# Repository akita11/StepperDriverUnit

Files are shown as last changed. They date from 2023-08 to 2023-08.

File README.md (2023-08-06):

# SteppterDriverUnit

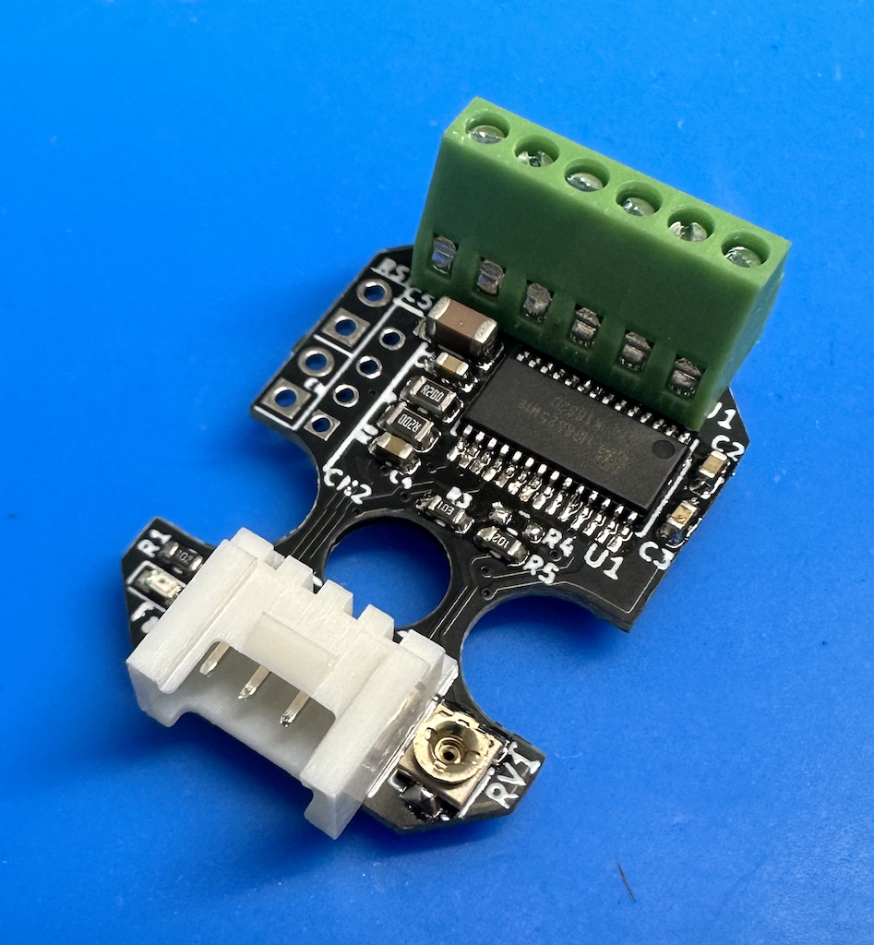
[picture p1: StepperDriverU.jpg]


ステッピングモータをGrove端子からの方向・パルスのみで制御できるUNITです。ドライバICはよく使われるDRV8825の互換IC(HR8255)を使用しており、マイクロステップ駆動も可能です。またイネーブル・リセットは別の端子から与えることもできます。

# 使用法（まずは使ってみる）

- 6pコネクタ（ネジ端子：基板裏面にシルク表記あり）に、ステッピングモータの電源(+12V等）とモータのA相・B相(各2本：計4本）のケーブルを接続します。
- Grove端子にマイコンなど(M5Stack等)を接続します（ここからの+5V給電が本体の動作に必要です）
- Grove端子の信号線(DIRとSTP)でモータの回転の向きとステップを制御します。DIR=0/1で回転方向を決定し（実際の回転方向がどちらが時計回りかはA相・B相の配線によって異なる）、STPの立ち上がり（0→1の変化)で1ステップ進みます。

Grove端子のピン配置（基板裏面にシルク表記あり）： STP/DIR/+5V/GND

# 使用法（詳細な設定など）

半固定抵抗（RV1）でモータの駆動電流を設定てきます。また動作異常時にはD1(Fault)が点灯します。

## 補助制御端子

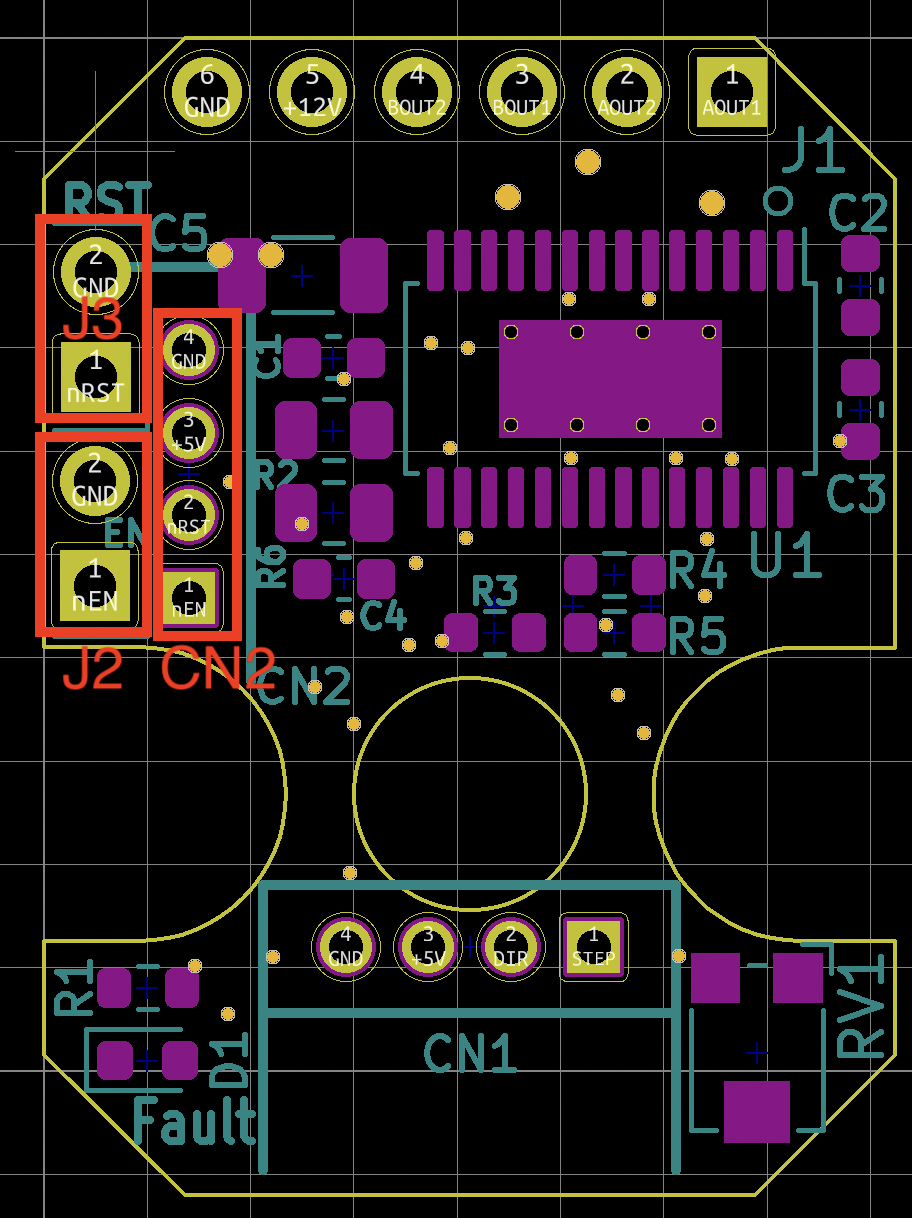
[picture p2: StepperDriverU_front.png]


- J2の2本をショートすると、ドライバICをdisable状態にしてモータの駆動をOFFにします。
- J3の2本をショートすると、ドライバICの内部状態をリセットします。
- CN2にもこの2本の信号線が引き出してあり、Grove端子をとりつけてマイコン等から制御することができます。このGrove端子のピン配置（基板裏面にシルク表記あり）： nEN/nRST/+5V/GND （nEN=0でドライバICがON、=1でOFF。nRST=0でドライバICをリセット、=1で通常動作）

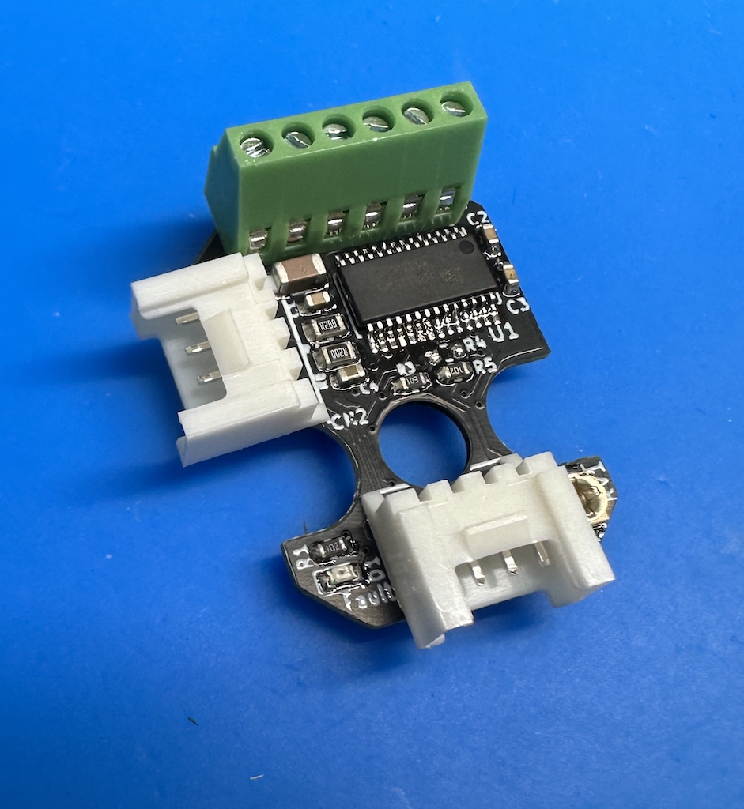
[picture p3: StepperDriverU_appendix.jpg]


## 駆動方法の設定

基板裏面の4つのソルダージャンパで、モータの駆動方法を設定できます。詳細はHR8825（またはDRV8825）のデータシートを参照してください。

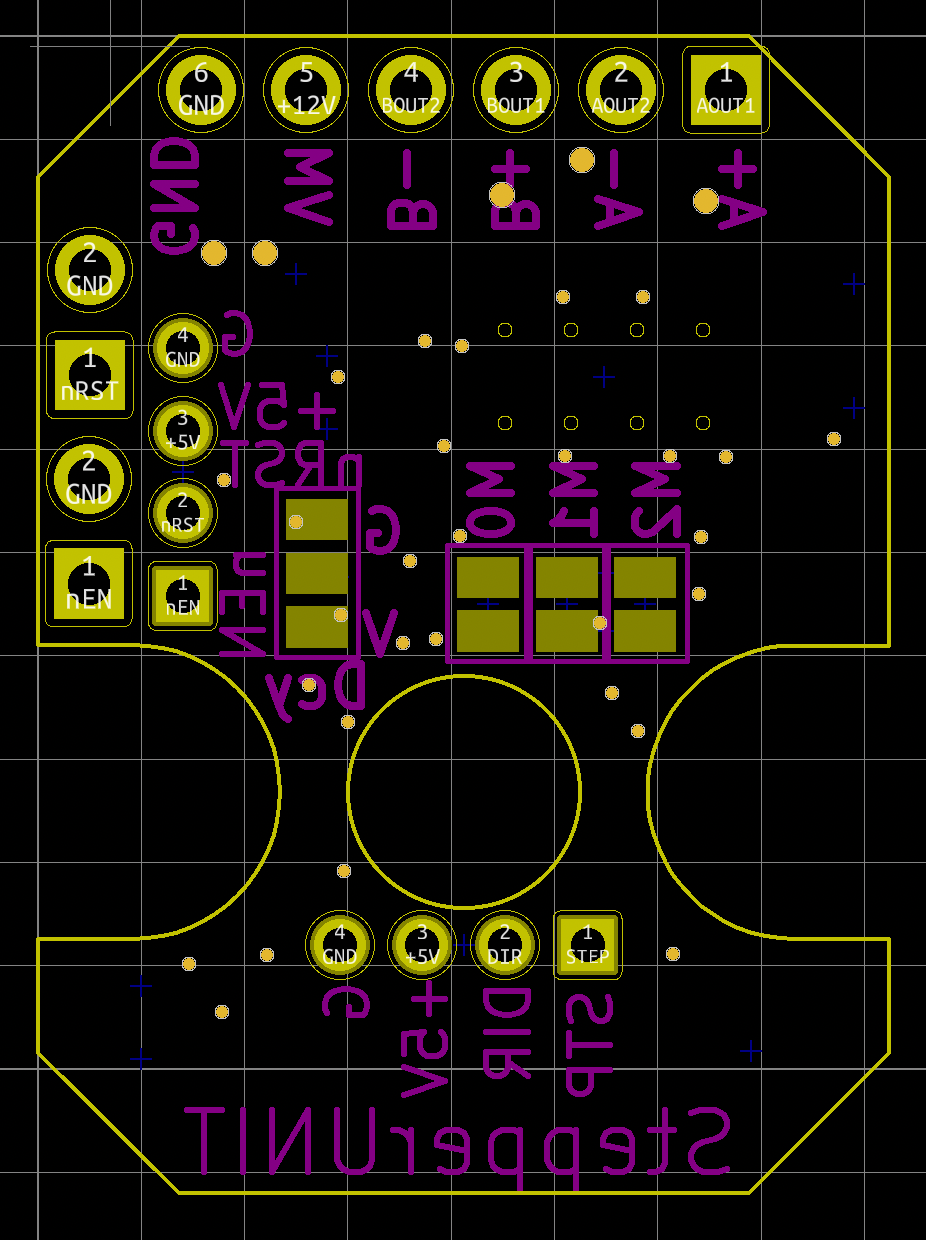
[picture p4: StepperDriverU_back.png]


- M0/M1/M2: マイクロステップの設定。（o=ショート、x=開放）

| M0 | M1 | M2 | マイクロステップ |
| -- | -- | -- | -- |
| x  | x  | x  | フルステップ |
| o  | x  | x  | 1/2ステップ |
| x  | o  | x  | 1/4ステップ |
| o  | o  | x  | 8 microステップ |
| x  | x  | o  | 16 microステップ |
| o  | x  | o  | 32 microステップ |
| x  | o  | o  | 32 microステップ |
| o  | o  | o  | 32 microステップ |

- Dcy: Decayモードの設定（G-中央間をショート=slow / V-中央間をショート=fast / ショートなし=mixed）

# Author

Junichi Akita (akita@ifdl.jp / @akita11)

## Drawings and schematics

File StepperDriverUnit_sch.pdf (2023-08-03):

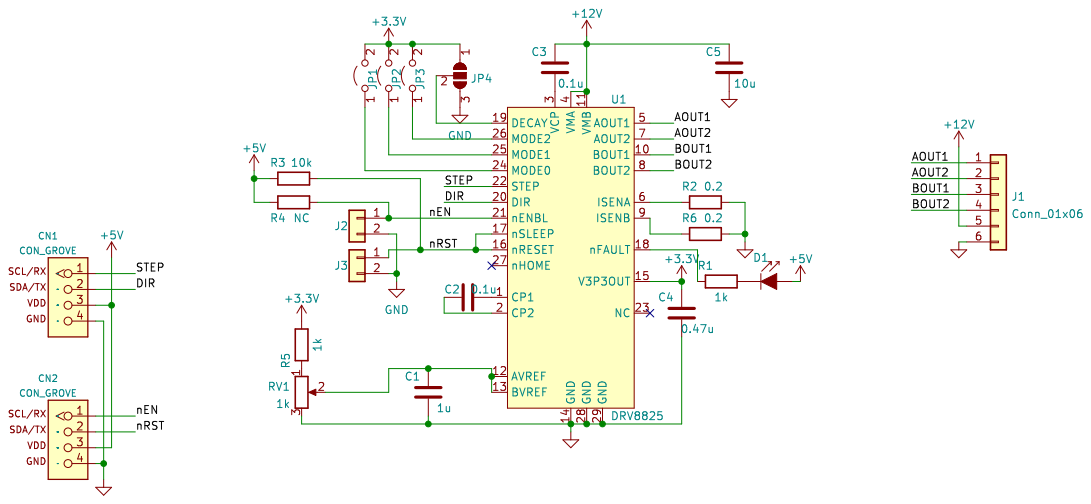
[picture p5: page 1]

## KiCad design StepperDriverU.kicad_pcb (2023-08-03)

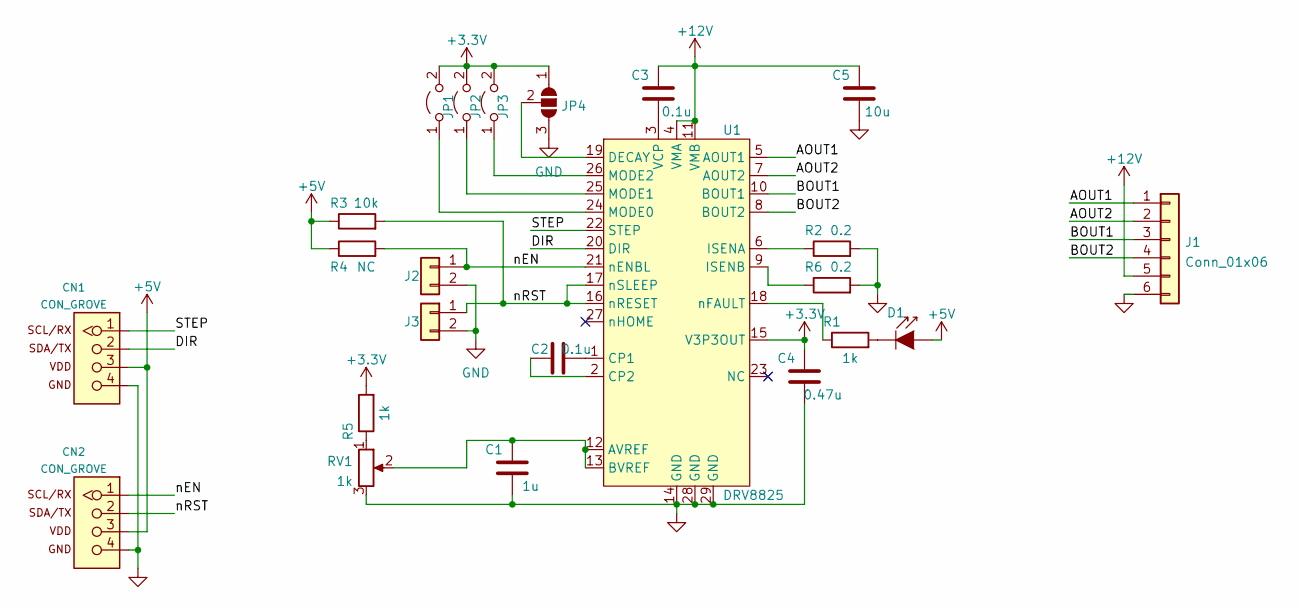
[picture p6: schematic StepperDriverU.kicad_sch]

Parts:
C1: 1u; C_0603_1608Metric
C2, C3: 0.1u; C_0603_1608Metric
C4: 0.47u; C_0603_1608Metric
C5: 10u; C_1206_3216Metric
CN1, CN2: CON_GROVE; CON_GROVE_H
D1: LED; LED_0603_1608Metric
J1: Conn_01x06; PinSocket_1x06_P2.54mm_Vertical
J2, J3: Conn_01x02; PinSocket_1x02_P2.54mm_Vertical
JP1, JP2, JP3: Jumper_2_Open; SolderJumper-2_P1.3mm_Open_Pad1.0x1.5mm
JP4: SolderJumper_3_Open; SolderJumper-3_P1.3mm_Open_Pad1.0x1.5mm
R1, R5: 1k; R_0603_1608Metric
R2, R6: 0.2; R_0805_2012Metric
R3: 10k; R_0603_1608Metric
R4: NC; R_0603_1608Metric
RV1: 1k; Potentiometer_Bourns_TC33X_Vertical
U1: DRV8825; HTSSOP-28-1EP_4.4x9.7mm_P0.65mm_EP2.85x5.4mm_ThermalVias

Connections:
+3V3: C4.2, JP1.2 (B), JP2.2 (B), JP3.2 (B), JP4.1 (A), R5.2, U1.15 (V3P3OUT)
+5V: CN1.3, CN2.3, D1.2 (A), R3.1, R4.1
+12V: C3.2, C5.2, J1.5, U1.4 (VMA), U1.11 (VMB)
/AOUT1: J1.1, U1.5 (AOUT1)
/AOUT2: J1.2, U1.7 (AOUT2)
/BOUT1: J1.3, U1.10 (BOUT1)
/BOUT2: J1.4, U1.8 (BOUT2)
/DIR: CN1.2, U1.20 (DIR)
/STEP: CN1.1, U1.22 (STEP)
/nEN: CN2.1, J2.1, R4.2, U1.21 (nENBL)
/nRST: CN2.2, J3.1, R3.2, U1.16 (nRESET), U1.17 (nSLEEP)
GND: C1.1, C4.1, C5.1, CN1.4, CN2.4, J1.6, J2.2, J3.2, JP4.3 (B), R2.2, R6.2, RV1.3, U1.14 (GND), U1.28 (GND), U1.29 (GND)
unnamed: C1.2, RV1.2, U1.12 (AVREF), U1.13 (BVREF)
unnamed: C2.1, U1.2 (CP2)
unnamed: C2.2, U1.1 (CP1)
unnamed: C3.1, U1.3 (VCP)
unnamed: D1.1 (K), R1.2
unnamed: JP1.1 (A), U1.24 (MODE0)
unnamed: JP2.1 (A), U1.25 (MODE1)
unnamed: JP3.1 (A), U1.26 (MODE2)
unnamed: JP4.2 (C), U1.19 (DECAY)
unnamed: R1.1, U1.18 (nFAULT)
unnamed: R2.1, U1.6 (ISENA)
unnamed: R5.1, RV1.1
unnamed: R6.1, U1.9 (ISENB)

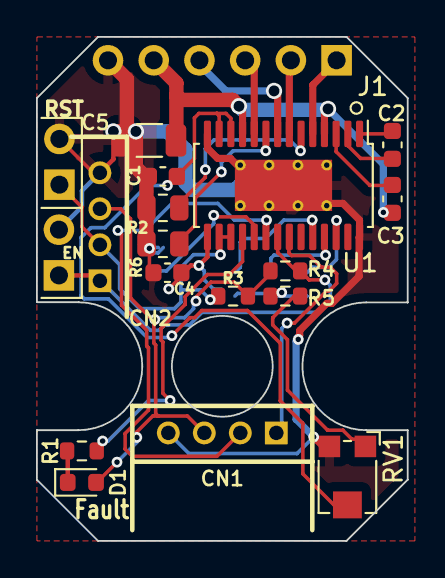
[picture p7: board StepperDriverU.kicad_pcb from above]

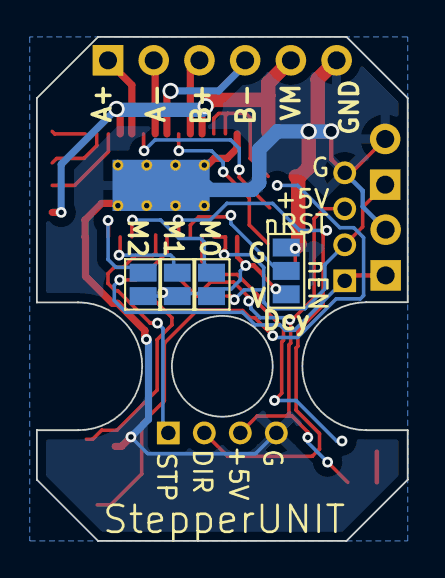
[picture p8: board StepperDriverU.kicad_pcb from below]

Board: 2 copper layers, 20.6 x 28.0 mm, 23 parts (4 on the bottom side), 25 nets.
